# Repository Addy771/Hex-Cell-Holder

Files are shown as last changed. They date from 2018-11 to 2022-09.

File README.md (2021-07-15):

# Hex-Cell-Holder
A parametric OpenSCAD project to generate STLs models of hexagonal lithium cell holders, boxes, and caps to be 3d printed.

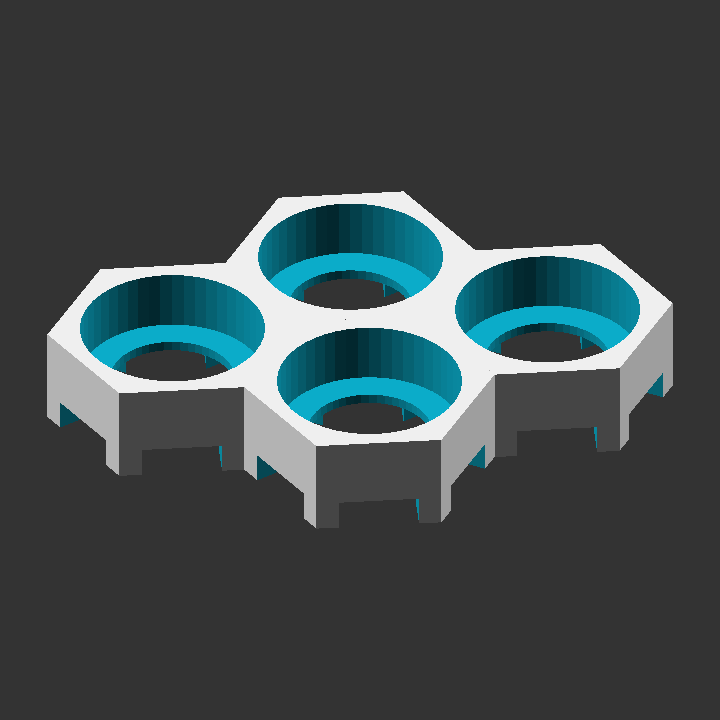
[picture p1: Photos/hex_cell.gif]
Parametric

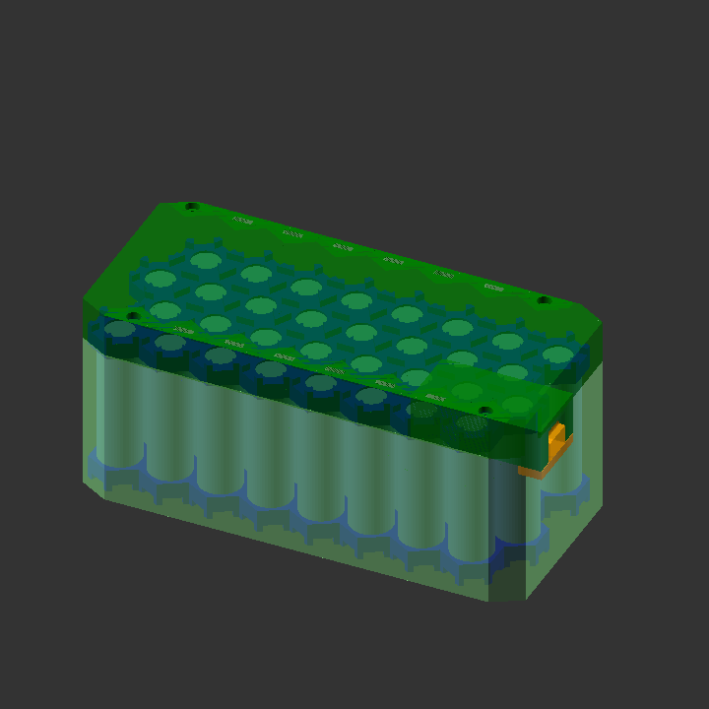
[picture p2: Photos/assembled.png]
Assembled

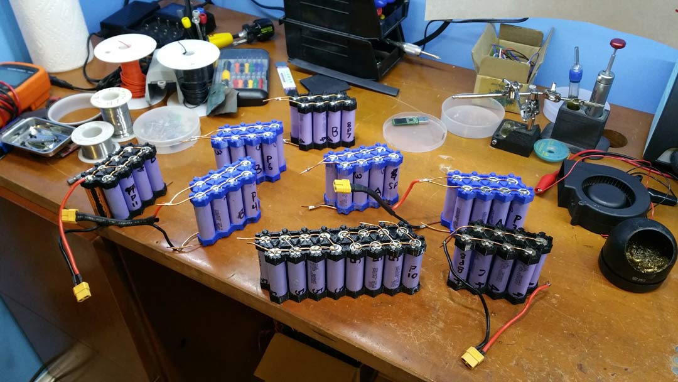
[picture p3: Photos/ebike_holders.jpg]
EBike battery pieces

8p Packs for an ebike
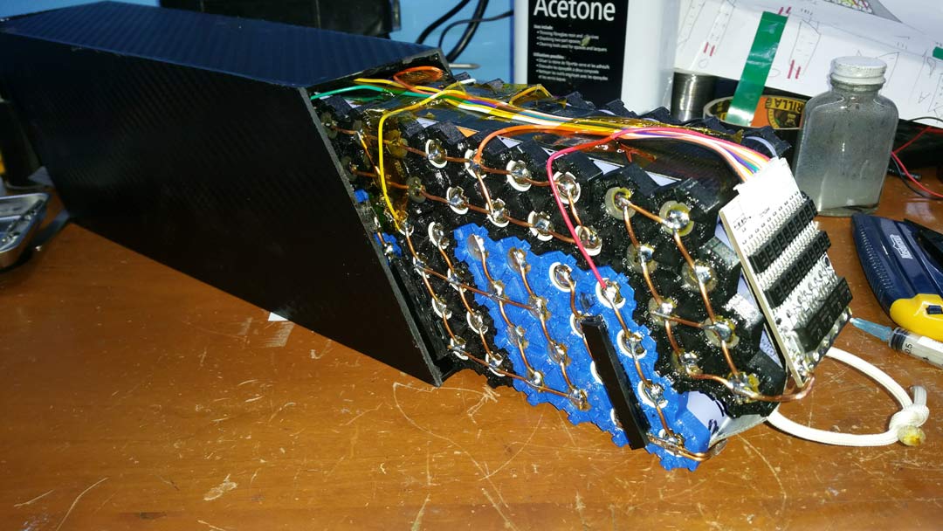
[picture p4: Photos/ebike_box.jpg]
Ebike Battery box

Box made of ABS sheet
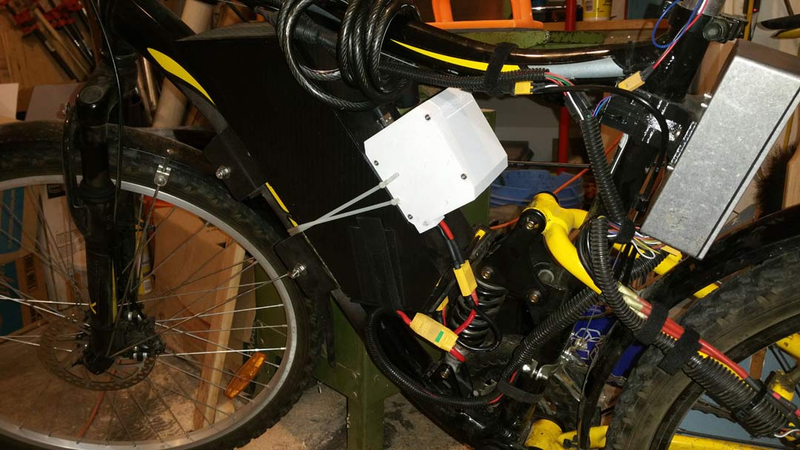
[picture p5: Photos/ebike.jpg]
Ebike

10s and a 2s box connected in series.
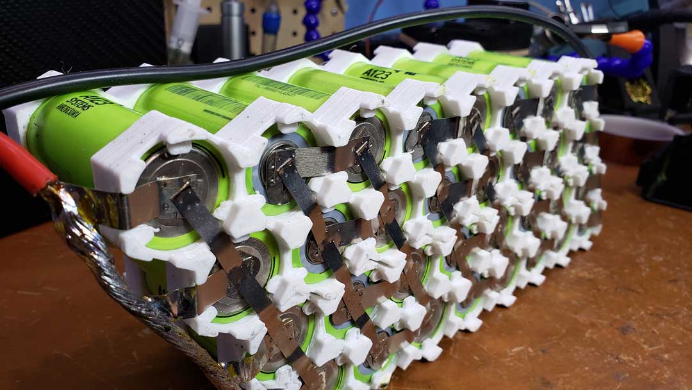
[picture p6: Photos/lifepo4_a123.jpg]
Lifepo4 A123 Cells

Large A123 Lifepo4 cells
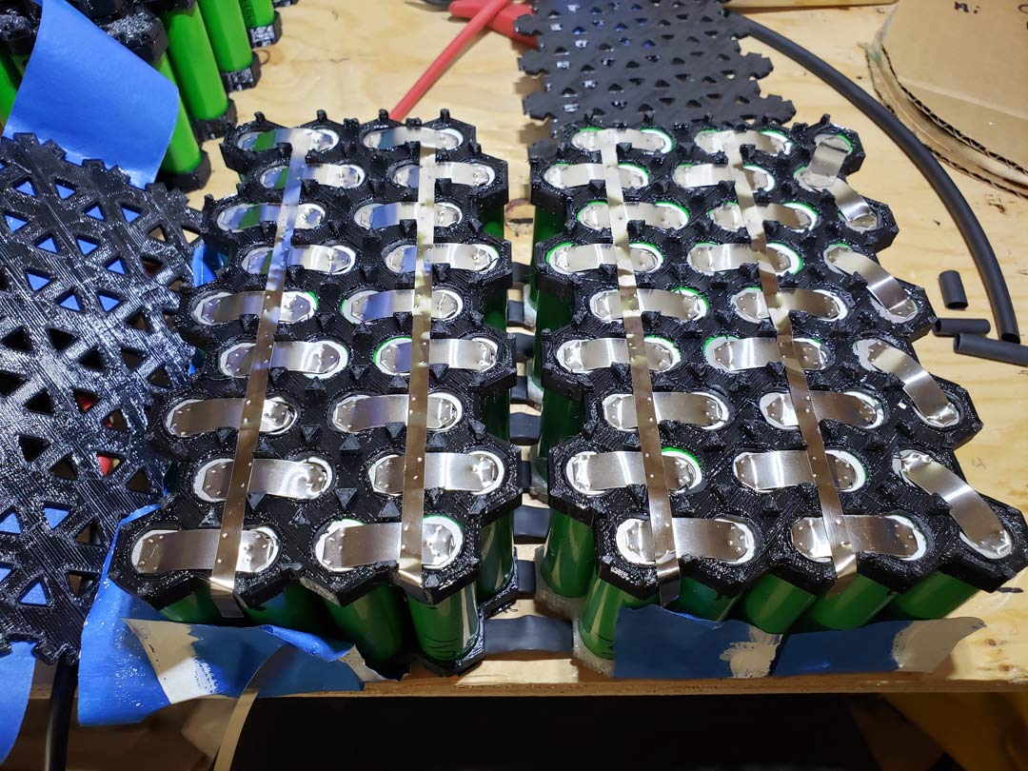
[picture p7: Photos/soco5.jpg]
soco5

Part of a Battery for the Soco TC motocycle
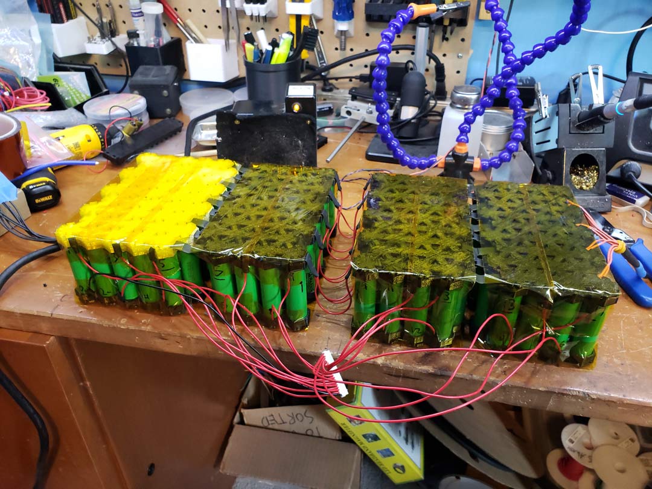
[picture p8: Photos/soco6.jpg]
soco6


## How does it work?
Hex-Cell-Holder uses OpenSCAD to create solid 3D CAD objects. Openscad allows easy parametric configuration of a 3d model which means you don't need to be a coder to create a specific model that you need.

http://www.openscad.org/

## Who should use this?
This project was primarily created to make lithium ion packs out of 18650 for ebikes with the help of a 3d printer. You can make **any size** pack you want out of **any size** cylindrical lithium cell. 

## Holders

You can generate a holder of any number of rows, columns, rectangular or parallelogram, and strip or bus. Below is an example configuration.
Check the console for extra information like whether or not you need a mirrored holder or total widths or lengths.

## Caps
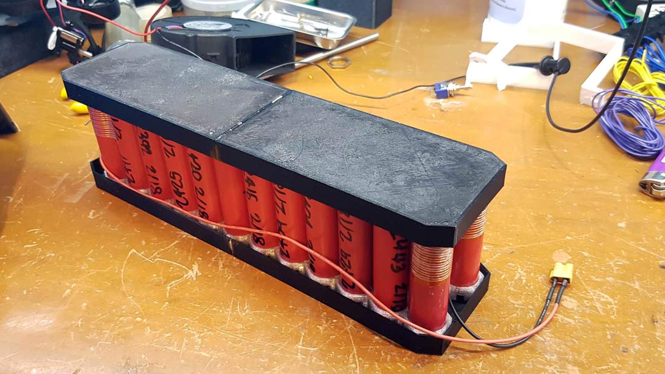
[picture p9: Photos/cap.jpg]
Battery With Caps

Caps can be generated to fit over the holders for when you don't need a full box to house the pack but still want the terminals safely covered.

## Boxes and wire clamp
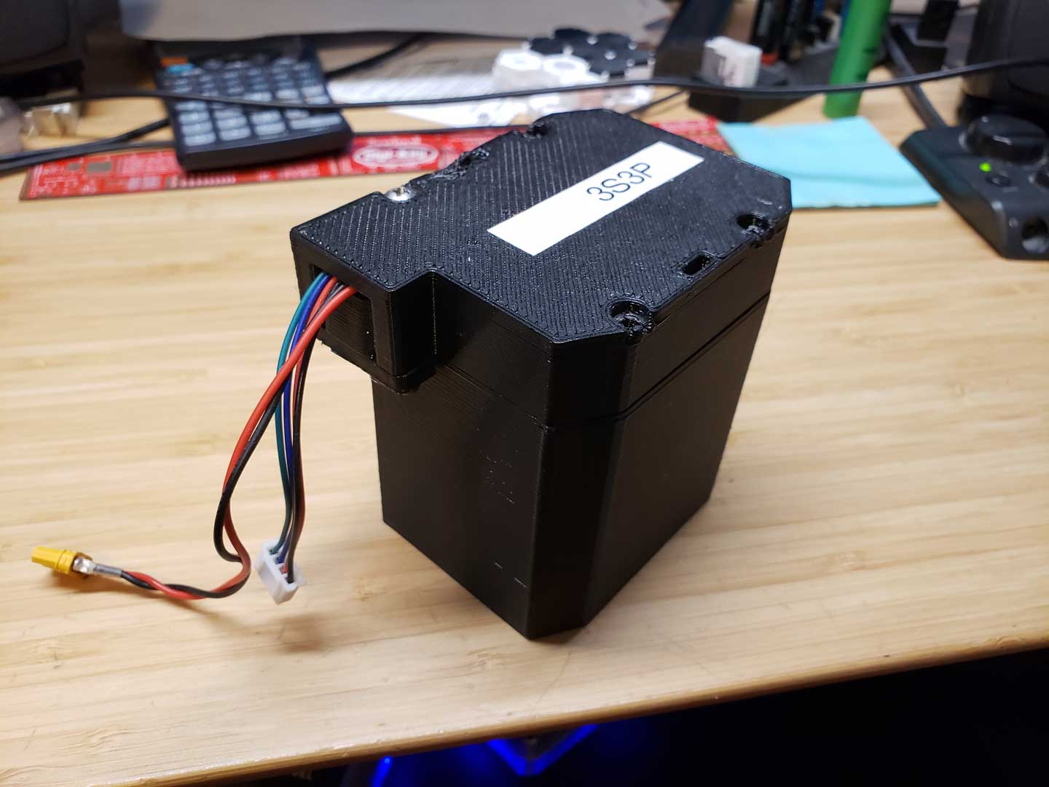
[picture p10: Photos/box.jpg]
Box

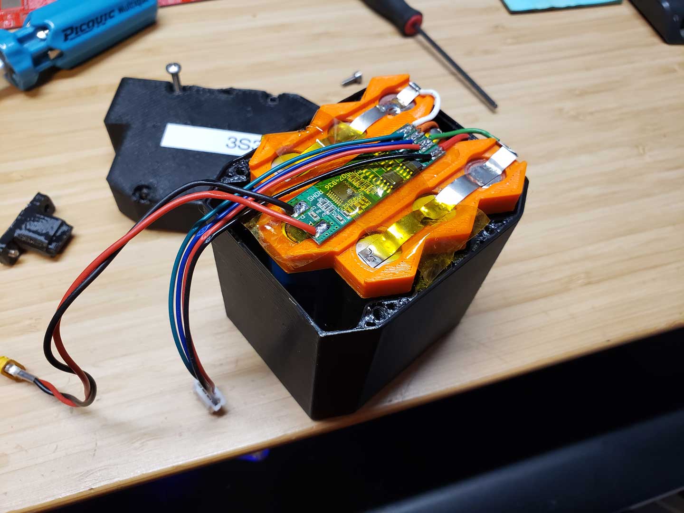
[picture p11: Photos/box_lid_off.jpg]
Box with lid off

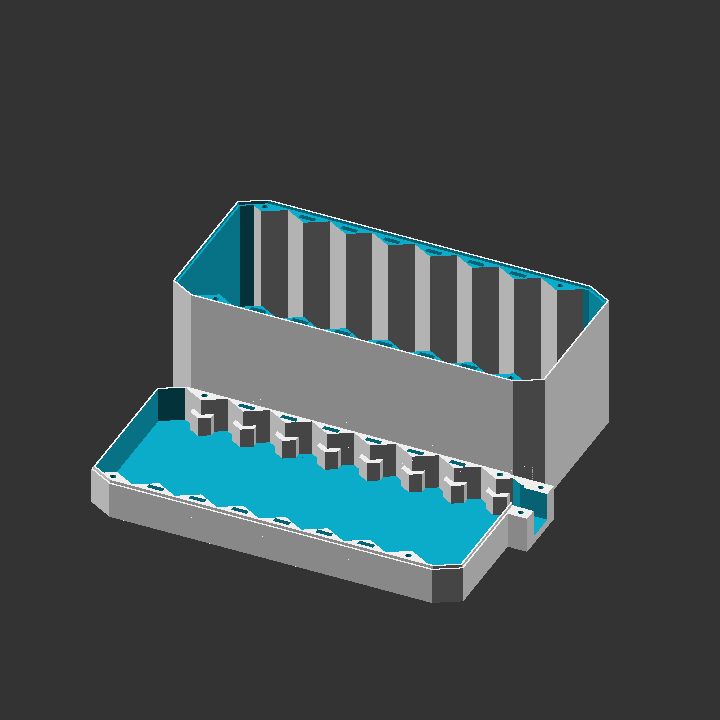
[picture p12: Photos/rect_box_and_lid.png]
Rect Box and lid

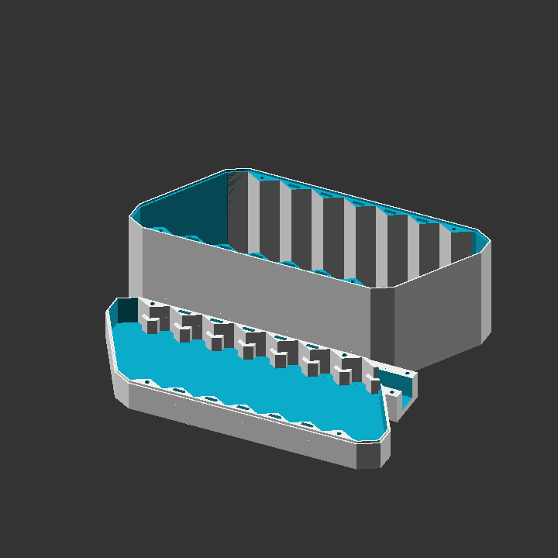
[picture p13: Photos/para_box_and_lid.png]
Para Box and lid


Your battery pack can be put into a box to be fully enclosed and protected. There is also a wire clamp for your bulk leads to provide some strain relief. The box has many options so read through the config to see what you can do.
## Printing an insulator as support
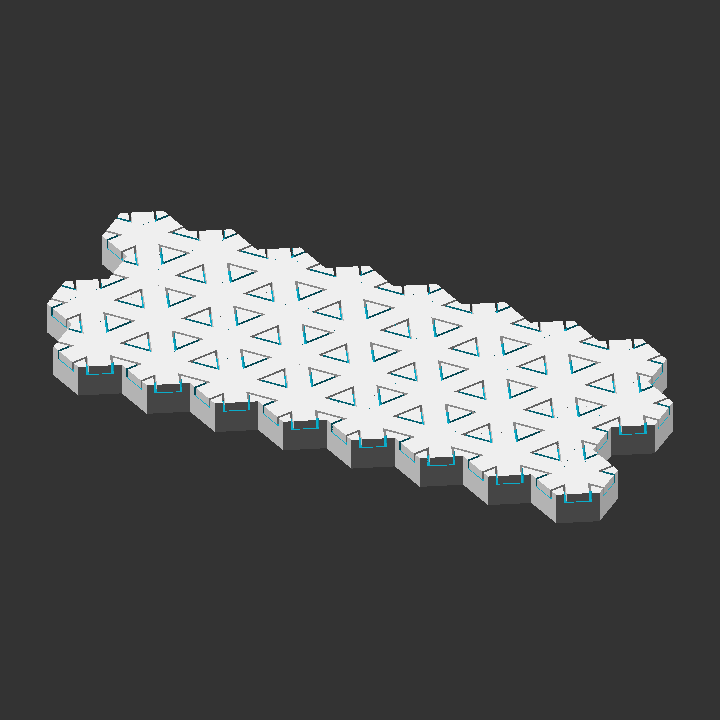
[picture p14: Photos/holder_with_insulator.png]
Holder with Insulator as support


This option allows you to print the support you would normally have to remove as a insulator to put over the strips afterwards for extra protection.
It is very easy to remove and I would recommend enabling it for that reason alone however it will use up more plastic.

# Fit test
fit_test.scad generates holders to test fit which cell_dia to use for the holders.

# Bat scripts to generate stls
Bat files are added to quickly generate multiple stls. This saves a lot of time by not having to change part_type and part, rendering, and then exporting as an stl for each piece.

# Experimental features
## Vertical Holder and Box Stacking
There are some options for stacking packs vertically. Stacking pins/holes allow holders to stack into each other. Stacking bolts create holes in the holders so the entire pack can be bolted together. Please read safety issues with these experimental options in the openscad file.

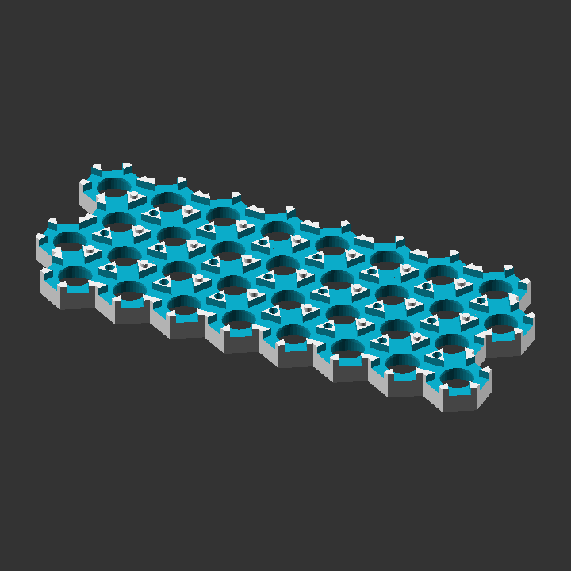
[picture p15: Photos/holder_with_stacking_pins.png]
Stackingpins

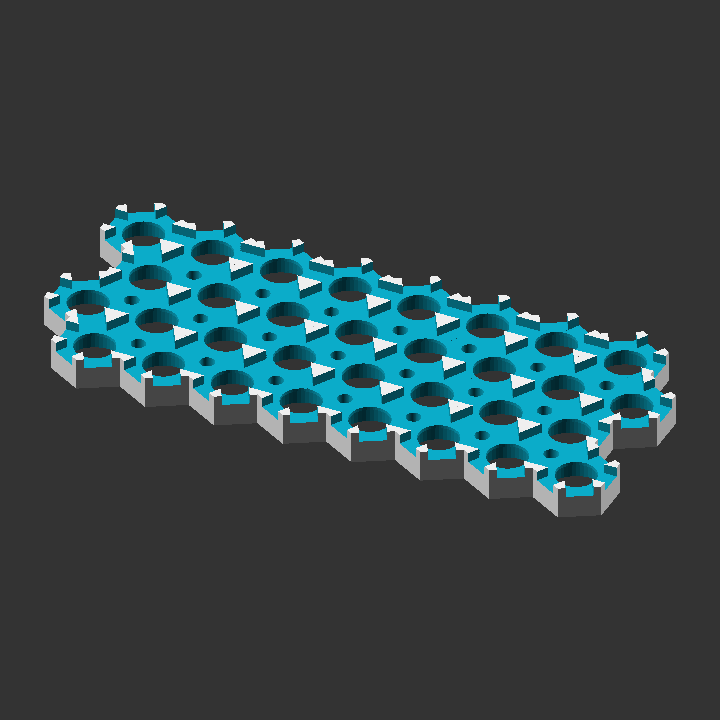
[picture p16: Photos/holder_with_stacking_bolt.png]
Stackingbolts


You can print out vertical box sections which increase the box height by one stack each.

# Donation/Photos
If you wish to donate you can use paypal.me/phana762 or bc1qhmggnntyk0vyvqffhl90nl532qqffa2dc3la5y for BTC. Thank you! 
We would love to see your battery builds too! Send us a photo/make at https://www.thingiverse.com/thing:3029966

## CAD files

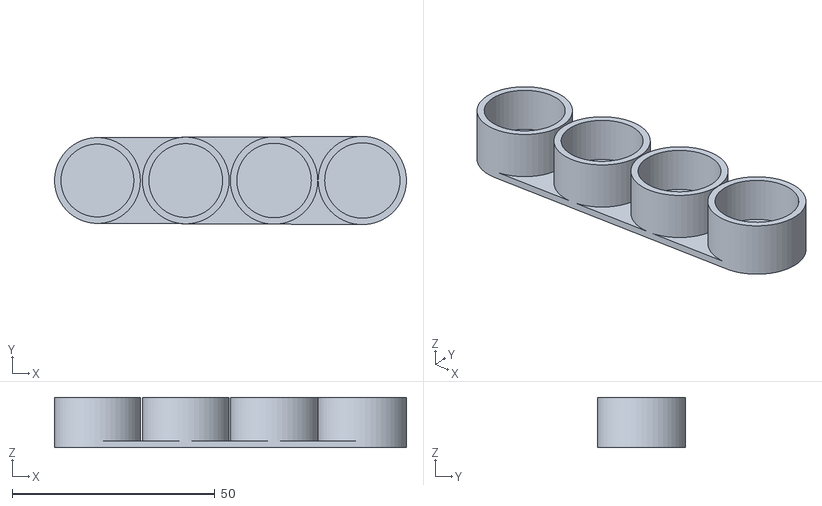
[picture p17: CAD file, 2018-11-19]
fit_test_18_18.2_18.4_18.6.stl
86.9 x 21.8 x 12.4

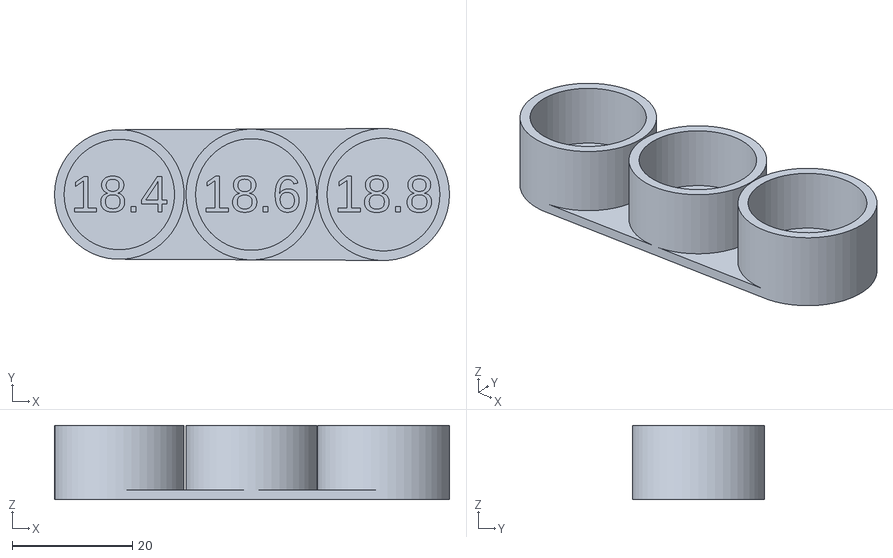
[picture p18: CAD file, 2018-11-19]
fit_test_18.4_18.6_18.8.stl
65.8 x 22.0 x 12.4

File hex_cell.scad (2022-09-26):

// https://github.com/Addy771/Hex-Cell-Holder
// This script generates models of cell holders and caps for
// building battery packs using cylindrical cells.
// Original concept by ES user "SpinningMagnets"
// More info can be found here:
// https://endless-sphere.com/forums/viewtopic.php?f=3&t=90058
//
// This file was created by Addy and is released as public domain
// Contributors
// Albert Phan - Added boxes, stacking, and optimizations


///////////////////////////////////////////////////////////////////////////////////////////////////////////
// BASIC CONFIGURATION
/////////////////////////////////////////////////////////////////////////////////////////////////////////////


cell_dia = 18.4;    // Cell diameter default = 18.4 for 18650s **PRINT OUT TEST FIT PIECE STL FIRST**
cell_height = 65;	// Cell height default = 65 for 18650s
wall = 1.2;       // Wall thickness around a single cell. Make as a multiple of the nozzle diameter. Spacing between cells is twice this amount. default = 1.2
					// If using bought injection molded hexes and printing out the boxes, take the distance between the centers of 2 cells and divide by two for the wall thickness (((((pitch - diameter)/2). Add space for the protuding interlocking tabs in the cap or box clearances.

num_rows = 4;
num_cols = 8;

holder_height = 10; // Height of cell holder default = 10 (not including slot_height)
slot_height = 3;  // Height of all slots default = 3 mm (set to 0 for no slots but that allows you to print without support)

col_slot_width = 8; // Width of slots between rows default = 8
row_slot_width = 8; // Width of slots along rows default = 8


pack_style = "rect";	// "rect" for rectangular pack, "para" for parallelogram, "tria" for triangle shaped pack (number of rows define the amount of rows at the bottom of the triangle. Columns get ignored)

wire_style = "strip";	// "strip" to make space to run nickel strips between cells. Default usage
						// "bus" to make space for bus wires between rows

box_style = "both";		// "bolt" for bolting the box pack together
						// "ziptie" for using zipties to fasten the box together. (ziptie heads will stick out),
						// "both" default: uses bolts for the 4 corners and zipties inbetween. Useful for mounting the pack to something with zipties but while still using bolts to hold it together 

part_type = "normal";   // "normal","mirrored", or "both". "assembled" is used for debugging.  You'll want a mirrored piece if the tops and bottom are different ( ie. When there are even rows in rectangular style or any number of rows in parallelogram. The Console will tell you if you need a mirrored piece).

part = "holder";   		// "holder" to generate cell holders,
						// "cap" to generate pack end caps,
						// "box lid" to generate box lid
						// "box bottom" for box bottom
						// "wire clamp" for strain relief clamp
						// "insulator" for insulator piece to fit over the nickel strips
						// "vertical box section" for vertical battery stacking boxes (print 1 section for every additional stacked pack) 

box_lip = true;			// Adds a lip to the box pieces. default = true.
wire_clamp_add = true; 	// Adds a wire exit hole out the side of the box lid.
insulator_as_support = true;	// Print the insulator as a part of the holder support material.

cap_wall = 1.2;				// Cap wall thickness (default = 1.2 recommend to make a multiple of nozzle dia)
cap_clearance = 0.2;		// Clearance between holder and caps default = 0.2

box_wall = 2;				// Box wall thickness (default = 2.0 recommend to make at least 4 * multiple of nozzle dia)
box_clearance = 0.2;		// Clearance between holder and box default = 0.2


// Box clearances for wires
bms_clearance = 10; 			// Vertical space for the battery management system (bms) on top of holders, set to 0 for no extra space
box_bottom_clearance = 0;	// Vertical space for wires on bottom of box
box_wire_side_clearance = 3; // Horizontal space from right side (side with wire hole opening) to the box wall for wires
box_nonwire_side_clearance = 0; // Horizontal space from left side (opposite of wire hole) to the box wall for wires

support_z_gap = 0.3;		// Insulator gap to holder. default 0.3
insulator_tolerance = 1.5;	// How much smaller to make the width of the insulator default 1.5
insulator_thickness = (slot_height-support_z_gap);	// Thickness of insulator

wire_diameter = 5;			// Diameter of 1 power wire used in the strain relief clamps default = 5 for 10 awg stranded silicon wire
wire_clamp_bolt_dia = 3;	// Bolt dia used for clamping wire default = 3 for M3 bolt
clamp_factor = 0.7;			// Factor of wire diameter to be clamped. Higher number is less clamping force (default=0.7 max=1.0)
bolt_dia = 3;				// Actual dia of bolt default = 3 for M3 bolt
bolt_head_dia = 6;			// Actual dia of bolt head default = 6 for M3 socket head bolt
bolt_head_thickness = 3;	// Thickness (height) of bolt head default = 3 for M3 Socket head
ziptie_width = 8;
ziptie_thickness = 2.5;

////////////////////////////////////////////////////////////////////////////////////
// EXPERIMENTAL Vertical Holder Stacking
// Use at own risk - Stacking holders vertically requires more thought into electrical short prevention.
// For best use, col and row slots sizes should be the same so the pin is centered
// Rectangular packs only
// Using stacking pins or bolts require you to cut holes out for the kapton tape/fishpaper for the insulation.
// If you don't use stacking pins or bolts, you can print out insulators (use part = insulator) and add kapton/fishpaper without cutting holes in it on top.
// The fishpaper is a last line of protection to prevent shorts in case the plastic insulation melts due to a malfunction.
///////////////////////////////////////////////////////////////////////////////////

stacking_pins = false;	// Adds pins and holes for stacking holders vertically. Make sure col and row slots are the same width. You'll have to think about how to insulate the strips properly. Maybe precut kapton/fishpaper? 
stacking_pin_dia = 3;	// Default 3 mm. Smaller than 3 not recommended.
stacking_pin_alt_style = false; // Alternate style of pins that are longer and go into the holder deeper. (Used when the triangle islands are too small for a hole)
stacking_bolts = false;	// Adds holes through the holders to bolt them (if not using box to bolt them together). 
						// !!!!!!MAKE SURE BOLTS DO NOT SHORT NICKEL STRIPS!!!!
						// Don't use with stacking pins. You'll need mirrored pieces.
stacking_bolt_dia = 4.5;	// Bolt dia. Make slightly bigger for bolt fit. Watch out for too large bolts that cut too much out of the holder.
num_pack_stacks = 1;	// How many additional packs you will stack vertically. Affects part = vertical box section. (set to 1 if you just want to print single sections and glue them together. 1 section for every additional pack stack)



///////////////////////////////////////////////////////////////////////////////////
// ADVANCED CONFIGURATION for users that need to customize everything
//////////////////////////////////////////////////////////////////////////////////

cell_top_overlap = 3; // How big the opening overlaps the cell default = 3
opening_dia = cell_dia-cell_top_overlap*2;   		// Circular opening to expose cell
separation = 1;   			// Separation between cell top and wire slots (aka tab thickness) default = 1
wire_hole_width = 15;		// Width of wire hole default = 15
wire_hole_length = 10;		// Length of the wireclamp that sticks out default = 10
wire_top_wall = 4;			// Thickness of top wire wall default = 4mm
clamp_plate_height = 4;		// default = 4
bolt_dia_clearance = 1;		// Amount of extra diameter for bolt holes default = 1
box_lip_height = box_wall * 0.75;	// Height of lip default = box_wall * 0.75
box_lip_width = box_wall * 0.5;		// Width of lip default = box_wall * 0.5
stacking_pins_tolerance = 0.5;	// How much larger for the stacking pin hole compared to it's pin diameter
spacer_overhang = box_clearance + 3; 		// Amount of spacer overhang to hold the holders default = 3

flip_holders = false;	// Mostly used for taking pngs



// cell_tab_width = 5;			// Width of tab that keeps the cell in the holder default = 5
// cell_tab_length = 3;		// Approx Length of tab that keeps the cell in the holder default = 3

//////////////////////////////////////////////////////
// Don't forget to do a test fit print
//////////////////////////////////////////////////////

// END OF CONFIGURATION
////////////////////////////////////////////////////////////////////////
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

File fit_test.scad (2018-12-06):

// Generate a tool for checking optimal cell fit

size_list = [18.0,18.2,18.4,18.6]; // Add size to test in this array.

wall_thickness = 1.6;
cell_depth = 10;


union(){

    for(i = [0:len(size_list)-1])
    {
        
        translate([i*(max(size_list)+2*wall_thickness),0,0])
            cell_gauge(size_list[i]);

    }
    
    hull(){
        translate([0,0,-(cell_depth+wall_thickness)/2])
            cylinder(h=wall_thickness, d=size_list[0]+2*wall_thickness, center=true);
            //cylinder(h=wall_thickness, d=1, center=true);
        
        last_index = len(size_list)-1;
        translate([(max(size_list)+2*wall_thickness)*last_index,0,-(cell_depth+wall_thickness)/2])
            cylinder(h=wall_thickness, d=size_list[last_index]+2*wall_thickness, center=true);
            //cylinder(h=wall_thickness, d=1, center=true);
    }

}

$fn=50;

module cell_gauge(diameter)
{
    difference()
    {
        // Outer cylinder
        cylinder(h=cell_depth+wall_thickness, d=diameter+2*wall_thickness, center=true);
        
        // Cell cutout
        translate([0,0,wall_thickness/2+0.005])
            cylinder(h=cell_depth+0.01, d=diameter, center=true);
        
        // Embossed text
        translate([0,0,-(cell_depth/2-0.01)])
            linear_extrude(wall_thickness/2+0.01)
                text(str(diameter), size=diameter/3, halign="center", valign="center");
    
    }

};

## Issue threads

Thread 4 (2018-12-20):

Boxes with 2 columns or less and both hole styles selected generate bolt and ziptie holes together

AlbertPhan, 2018-12-20:
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

AlbertPhan, 2018-12-22:
Fixed in #7

Closed 2018-12-22.

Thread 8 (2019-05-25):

Cell removal obstructed

Addy771, 2019-05-25:
The current cell holder design has 3 tabs over each cell, which can be snapped off if a cell needs to be removed.

This won't work if a bus strip/wire passes over the cells. The bus will have to be removed first to make room for a cell to slide out.

One possible solution to this issue is to add extra space between cells, where the bus will be.

Addy771, 2019-05-25:
This image shows the problem. For wider bus conductors like strips this is more of a concern.

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

AlbertPhan, 2019-05-25:
What we can do is when the bus style is chosen, we can have the cells automatically spaced apart based on the bus width distance to make sure the cells aren't obstructed. I will implement this when I have free time.

AlbertPhan, 2021-07-14:
This feature was never really used so I am closing this issue.

Closed 2021-07-14.

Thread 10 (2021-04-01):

Parallelogram Boxes

tenten8401, 2021-04-01:
Any chance we could get boxes for parallelogram type batteries? Would be super useful for ebikes

AlbertPhan, 2021-07-14:
This has been added with #11.

tenten8401, 2021-07-15:
Awesome :)

tenten8401, 2021-07-15:
@AlbertPhan you got a link I could donate a couple bucks to?

AlbertPhan, 2021-07-15:
I have added a donation link to the end of the readme. Thanks!

Closed 2021-07-14.

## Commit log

2017-09-28 Update to V1.2
    Fixed separation thickness between cell top and tab slots.
    [hex_cell.scad]
2018-01-11 Added ability to create both pieces of holder at once
    You can choose between normal, mirrored, or both parts to be rendered.
    [hex_cell.scad]
2018-06-16 Added bus and strip styles and flipped part
    Bus and strip styles and flipped part for proper printing orientation.
    Added some warnings for when top and bottom parts were different.
    [hex_cell.scad]
2018-08-01 V1.4: added option to generate pack caps
    Updated configuration section and cleaned up code
    [hex_cell.scad]
2018-08-14 Fixed incorrect cap heights when choosing different cap_wall thicknesses
    Fixed incorrect cap heights when choosing different cap_wall thicknesses
    [hex_cell.scad]
2018-08-15 Fixed incorrect offset of caps in x and y directions
    You would normally not notice unless you had holders and caps rendered at the same time.
    [hex_cell.scad]
2018-08-18 Started Working on Ziptie supports
    Will need to optimize some code with hull() instead of minkowskis as im having a lot of trouble lining up things.
    [hex_cell.scad]
2018-08-20 Changed minkowski to hulls, fixed z origins of holders, added some helper functions
    added get_hex_length() and get_hex_length_pt()
    TODO
    fix hex_pt to not include 'extra' variable
    [hex_cell.scad]
2018-08-21 Added get_hex_center_points_rect() helper function and started on mock_pack()
    get_hex_center_points_rect() returns a list of the center points of the hexes, useful for quickly adding items to each pack such as mock cells.
    [hex_cell.scad]
2018-08-21 Completed mock_pack()
    mock_pack() creates a mock pack for visualization
    [hex_cell.scad]
2018-08-21 Completed wire hole for box lid
    This hole gives a place for the pack wires to come out
    [hex_cell.scad]
2018-08-21 Completed half of the ziptie supports
    Todo
    -mirror to other side of lid
    -add ziptie holes
    [hex_cell.scad]
2018-08-22 Added bolt holes as a box fastening type
    You can choose ziptie or bolt to fasten the pack together.
    [hex_cell.scad]
2018-08-22 Modified rect_cap() and added rect_cap_positive and negative and started on box bottom
    Modified rect_cap() to allow for differenty type of caps based on parameters
    Added Positive and negative versions of caps for ease use in difference()s
    Started working on box bottom.
    [hex_cell.scad]
2018-08-22 Box bottom completed
    TODO: Code cleanup and other general checks to make sure everything is working
    [hex_cell.scad]
2018-08-23 Added fastening option for both zipties and bolt holes. Plus other fixes.
    Fixed boxes with even rows not properly doing lid supports
    Fixed mock pack having the correct height
    Removed redundent bolt_hole_taps() and just improved bolt_holes() instead.
    [hex_cell.scad]
2018-08-27 Changed box wire hole to be more in line with holder. Adjust box lid height to middle of top holder.
    [hex_cell.scad]
2018-08-27 Added wire clearance for sides of boxes if desired.
    Also added extra assembled pieces for helping with debugging
    [hex_cell.scad]
2018-09-07 Added box lips
    Added parameters to rect_cap positive and negative to add clearances in the x or y directions.
    [hex_cell.scad]
2018-09-08 Added Spacer parameter to lid supports
    Now the bottom box has proper spacer using box_bottom_clearance.
    Also fixed a bug with lid supports not working with large box_clearance values.
    [hex_cell.scad]
2018-09-08 Fixed Lid supports for different clearances
    Fixed Lid supports to work properly with different box_nonwire_clearance and box_wire_clearances.
    Cleaned up some code to use hex().
    [hex_cell.scad]
2018-09-08 Finished box lid lips
    Fixed some lid supports cutouts.
    Removed unusable move() module.
    [hex_cell.scad]
2018-09-09 Added strain relief clamp
    [hex_cell.scad]
2018-09-10 Cleaned up configuration
    [hex_cell.scad]
2018-09-12 Optimized the caps modules and added para style for mock_pack()
    Changed how the caps are generated by generating larger hexes for the hull()s instead of moving the hexes around. This simplfies the code and makes it more robust.
    Para_cap() now functional with new optimized code.
    Mock_pack() now generates para packs.
    [hex_cell.scad]
2018-09-12 Optimized lid_support() using intersect() instead of difference()
    Using an intersect() saves a lot of code and should be more robust for future use.
    [hex_cell.scad]
2018-09-12 Cell Tab concept for strip_hex() completed
    Added a cell tab that can be cut out to allow the faulty cell in a pack to be taken out and replaced.
    [hex_cell.scad]
2018-11-19 Added cell tabs. echos, and bat stls
    [box_bottom.stl, box_lid.stl, cap.stl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]
2018-12-06 Added ebike battery pic
2018-12-06 Cleaning up comments
    [fit_test.scad, hex_cell.scad]
2018-12-21 Fixed issue #5
    -y lid_support() in both_lid_support() was reworked to be smarter in how it differences the pieces.
    [hex_cell.scad]
2018-12-21 Fix issue #3
    This issue was caused from the wire support generation.
    [hex_cell.scad]
2018-12-21 Fixed Issue #4
    Easy fix. Don't generate ziptie holes for 'both' style when 2 columns or less.
    [hex_cell.scad]
2018-12-21 Fixed Issue #6
    Also added a config option to have a lip or not on the boxes.
    [hex_cell.scad]
2018-12-22 Updated TODO
    [hex_cell.scad]
2019-11-28 Fixed cell tabs getting way of nickel strips
    Fixed cell tabs getting way of nickel strips.
    Cell tabs are also out of the way for bus connections as well.
    [hex_cell.scad]
2020-01-28 Add support for triangular style holder
    [hex_cell.scad]
2020-01-28 Update hex_cell.scad
    Fixed total length echo.
    [hex_cell.scad]
2021-04-22 Experimenting with locating pins for stacking
    Using a list to determine pin positions.
    TODO: Do the hole cuts and the pins. Remove triangle islands if needed.
    [hex_cell.scad]
2021-04-23 Stacking pins and bolts functionality complete
    Stacking pins and bolts have been added. Needs full testing but
    mirrored, normal, both part styles should be working for rectangular
    packs.
    Changed a few defaults.
    Changed holder to be proper print orientation to be printed (especially
    with stacking pins enabled).
    [hex_cell.scad]
2021-04-29 Added insulators part
    Insulators fit inside the nickel strip channels to insulate the pack.
    Very useful for vertical stacking holders.
    [hex_cell.scad]
2021-04-29 Adding Vertical box sections
    Added Vertical box sections for vertical stacking packs.
    [hex_cell.scad]
2021-04-30 Finished up vertical_box_section()
    Vertical Sections should be sized properly.
    Assembled debugging view for stacking packs added.
    [hex_cell.scad]
2021-05-27 Made Wire Clamp Exit Hole Optional
    [box_bottom.stl, hex_cell.scad]
2021-06-11 Fixed "Both" parts when using stacking pins
    [hex_cell.scad]
2021-07-06 cap() refactoring and also starting para boxes
    added strip_insulators for all styles
    [hex_cell.scad]
2021-07-10 Refactoring,renaming, and clearance fixes
    box_clearance has been fixed. It did not work at all before.
    Renamed a lot of the modules to more sensible names.
    Removed duplicate code for rect and para. Most things just require
    calling one module that handles different pack_styles.
    [hex_cell.scad]
2021-07-14 Fixed caps
    Added flipped holder png part for taking pngs
    [hex_cell.scad]
2021-07-14 Updated photos
    [box_bottom.stl, box_lid.stl, cap.stl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]
2021-07-14 added bus insulators
    [hex_cell.scad]
2021-07-14 Added assembled.png
2021-07-14 Insulator as support default to true
    [hex_cell.scad]
2022-09-26 Added Console output for hex cell midpoint distances
    Added #13
    [hex_cell.scad]
